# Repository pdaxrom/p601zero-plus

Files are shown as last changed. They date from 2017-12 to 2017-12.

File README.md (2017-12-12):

## Pyldin-601 compatible retrocomputer.

[History](docs/HISTORY.md)

### Overview hardware version 2.0:

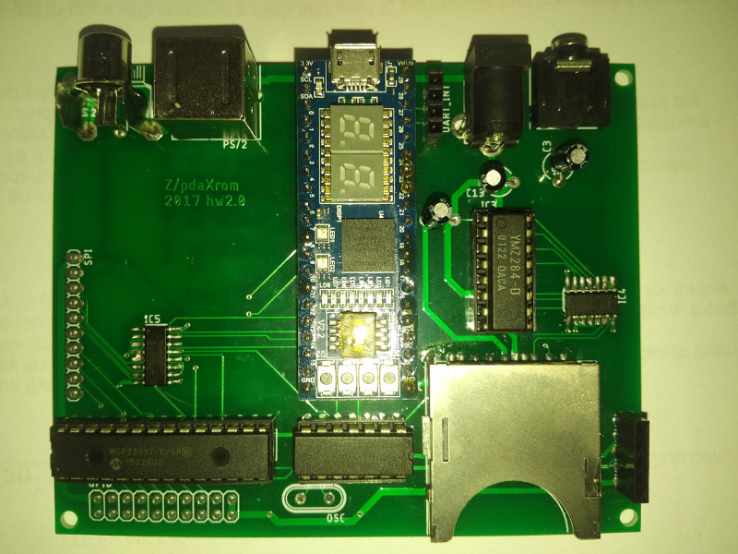
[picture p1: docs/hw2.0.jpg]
board version 2.0


 Function | Description 
----|----
CPU | [System 11 - VHDL 68HC11](http://members.optusnet.com.au/jekent/system11/)
FPGA| [Lattice MachXO2-4000HC module](http://www.stepfpga.com)
RAM | Builtin FPGA 4KB and/or external static serial ram 2x128KB
ROM | Builtin FPGA BOOTROM 2KB
Keyboard | PS/2
Serial port | 1 serial port and 1 UART (rx/tx only)
Parallel port | 2x8bit
Video | TV (color, 8bit DAC)
Audio | YMZ284-D (mono)
Storage | MMC/SD
Other | Onboard SPI, 4 CS ports and Reset.

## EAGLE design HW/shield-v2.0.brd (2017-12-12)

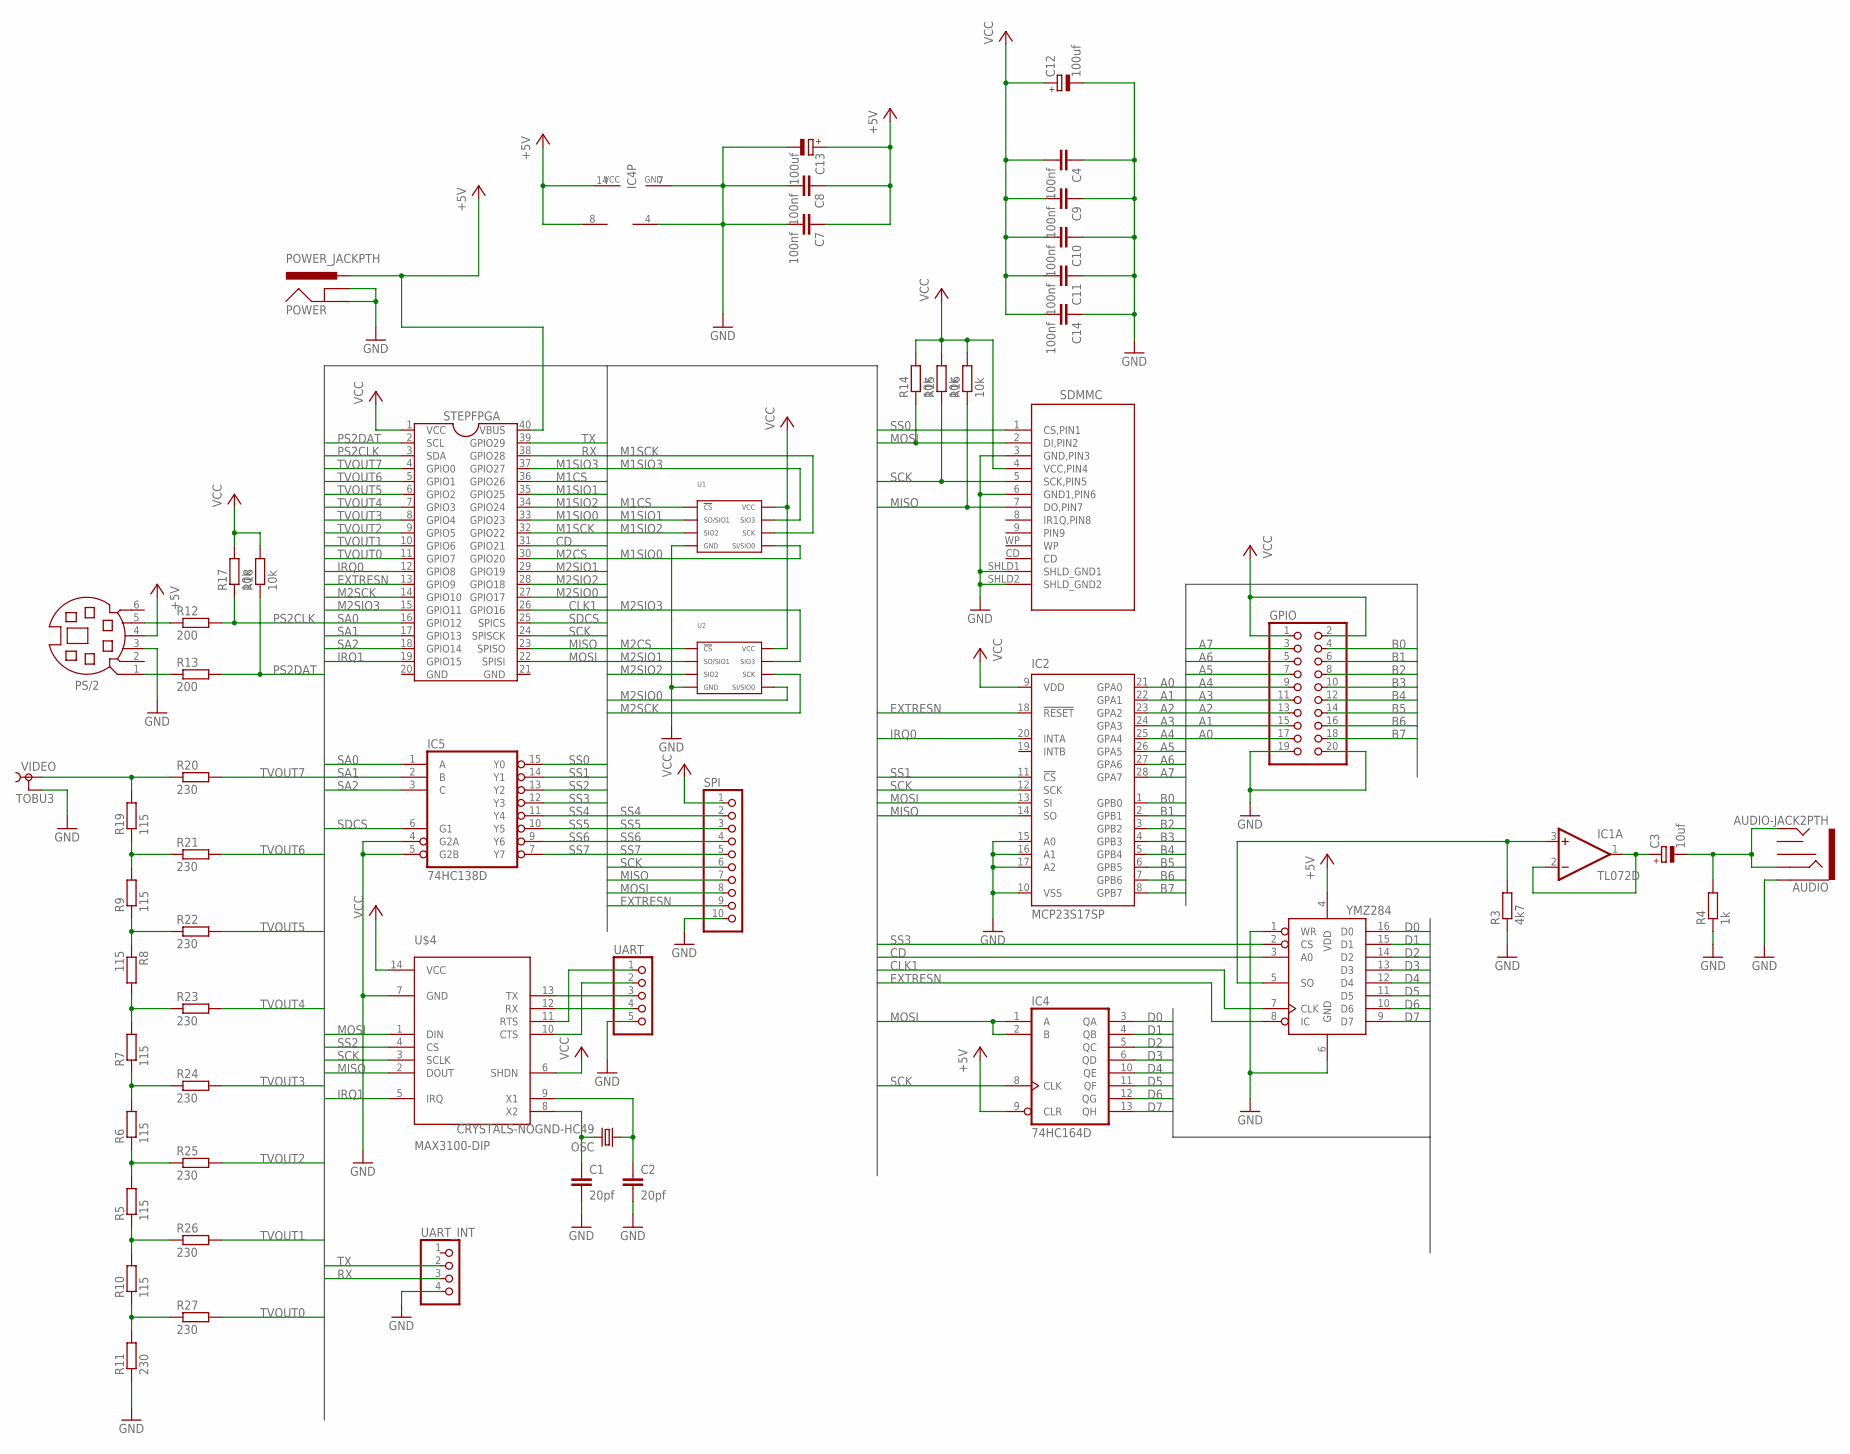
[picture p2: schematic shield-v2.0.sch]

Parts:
AUDIO: AUDIO-JACK2PTH; AUDIO-JACK
C1, C2: 20pf; 1206
C3: 10uf; E5-5
C4, C7, C8, C9, C10, C11, C14: 100nf; 1206
C12, C13: 100uf; E5-5
GPIO: PINHD-2X10; 2X10
IC1: TL072D; SO08
IC2: MCP23S17SP; DIL28-3
IC3: YMZ284; DIL16
IC4: 74HC164D; SO14
IC5: 74HC138D; SO16
OSC: CRYSTALS-NOGND-HC49; HC49
POWER: POWER_JACKPTH; POWER_JACK_PTH
PS/2: MD06SS; MDIN06SS
R3: 4k7; R1206
R4: 1k; R1206
R5, R6, R7, R8, R9, R10, R19: 115; R1206
R11, R20, R21, R22, R23, R24, R25, R26, R27: 230; R1206
R12, R13: 200; R1206
R14, R15, R16, R17, R18: 10k; R1206
SDMMC: FCI_SD_SOCKET; SD-MMC_SOCKET-PP
SPI: PINHD-1X10; 1X10
STEPFPGA: STEPFPGA; DIL40
U1, U2: 23A1024/23LC1024-I/SN; 23A1024_SOIC-8
U$4: MAX3100-DIP; DIL14
UART: PINHD-1X5; 1X05
UART_INT: PINHD-1X4; 1X04
VIDEO: TOBU3

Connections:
+5V: C7.1, C8.1, C13.+, IC1.8 (V+), IC3.4 (VDD), IC4.9 (CLR), IC4.14 (VCC), POWER.PWR, PS/2.4, STEPFPGA.40 (VBUS)
A0: GPIO.17, IC2.21 (GPA0)
A1: GPIO.15, IC2.22 (GPA1)
A2: GPIO.13, IC2.23 (GPA2)
A3: GPIO.11, IC2.24 (GPA3)
A4: GPIO.9, IC2.25 (GPA4)
A5: GPIO.7, IC2.26 (GPA5)
A6: GPIO.5, IC2.27 (GPA6)
A7: GPIO.3, IC2.28 (GPA7)
B0: GPIO.4, IC2.1 (GPB0)
B1: GPIO.6, IC2.2 (GPB1)
B2: GPIO.8, IC2.3 (GPB2)
B3: GPIO.10, IC2.4 (GPB3)
B4: GPIO.12, IC2.5 (GPB4)
B5: GPIO.14, IC2.6 (GPB5)
B6: GPIO.16, IC2.7 (GPB6)
B7: GPIO.18, IC2.8 (GPB7)
CD: IC3.3 (A0), STEPFPGA.31 (GPIO21)
CLK1: IC3.7 (CLK), STEPFPGA.26 (GPIO16)
D0: IC3.16 (D0), IC4.3 (QA)
D1: IC3.15 (D1), IC4.4 (QB)
D2: IC3.14 (D2), IC4.5 (QC)
D3: IC3.13 (D3), IC4.6 (QD)
D4: IC3.12 (D4), IC4.10 (QE)
D5: IC3.11 (D5), IC4.11 (QF)
D6: IC3.10 (D6), IC4.12 (QG)
D7: IC3.9 (D7), IC4.13 (QH)
EXTRESN: IC2.18 (!RESET), IC3.8 (IC), SPI.9, STEPFPGA.13 (GPIO9)
GND: AUDIO.SLEEVE, C1.2, C2.2, C4.1, C7.2, C8.2, C9.1, C10.1, C11.1, C12.-, C13.-, C14.1, GPIO.19, GPIO.20, IC1.4 (V-), IC2.10 (VSS), IC2.15 (A0), IC2.16 (A1), IC2.17 (A2), IC3.1 (WR), IC3.6 (GND), IC4.7 (GND), IC5.4 (G2A), IC5.5 (G2B), IC5.8 (GND), POWER.GND, POWER.GNDBREAK, PS/2.3, R3.1, R4.1, R11.1, SDMMC.3 (GND,PIN3), SDMMC.6 (GND1,PIN6), SDMMC.SHLD1 (SHLD_GND1), SDMMC.SHLD2 (SHLD_GND2), SPI.10, STEPFPGA.20 (GND), STEPFPGA.21 (GND), U1.4 (GND), U2.4 (GND), U$4.7 (GND), UART.5, UART_INT.4, VIDEO.2, VIDEO.2@1 (2), VIDEO.2@2 (2)
IRQ0: IC2.20 (INTA), STEPFPGA.12 (GPIO8)
IRQ1: STEPFPGA.19 (GPIO15), U$4.5 (IRQ)
M1CS: STEPFPGA.36 (GPIO26), U1.1 (CS')
M1SCK: STEPFPGA.32 (GPIO22), U1.6 (SCK)
M1SIO0: STEPFPGA.33 (GPIO23), U1.5 (SI/SIO0)
M1SIO1: STEPFPGA.35 (GPIO25), U1.2 (SO/SIO1)
M1SIO2: STEPFPGA.34 (GPIO24), U1.3 (SIO2)
M1SIO3: STEPFPGA.37 (GPIO27), U1.7 (SIO3)
M2CS: STEPFPGA.30 (GPIO20), U2.1 (CS')
M2SCK: STEPFPGA.14 (GPIO10), U2.6 (SCK)
M2SIO0: STEPFPGA.27 (GPIO17), U2.5 (SI/SIO0)
M2SIO1: STEPFPGA.29 (GPIO19), U2.2 (SO/SIO1)
M2SIO2: STEPFPGA.28 (GPIO18), U2.3 (SIO2)
M2SIO3: STEPFPGA.15 (GPIO11), U2.7 (SIO3)
MISO: IC2.14 (SO), R16.1, SDMMC.7 (DO,PIN7), SPI.7, STEPFPGA.23 (SPISO), U$4.2 (DOUT)
MOSI: IC2.13 (SI), IC4.1 (A), IC4.2 (B), R14.1, SDMMC.2 (DI,PIN2), SPI.8, STEPFPGA.22 (SPISI), U$4.1 (DIN)
unnamed: C1.1, OSC.2, U$4.8 (X2)
unnamed: U$4.13 (TX), UART.3
unnamed: U$4.12 (RX), UART.4
unnamed: U$4.11 (RTS), UART.1
unnamed: U$4.10 (CTS), UART.2
unnamed: C2.1, OSC.1, U$4.9 (X1)
unnamed: IC1.3 (+IN), IC3.5 (SO), R3.2
unnamed: C3.+, IC1.1 (OUT), IC1.2 (-IN)
unnamed: R19.2, R20.1, VIDEO.1
unnamed: AUDIO.RING, AUDIO.TIP, C3.-, R4.2
unnamed: R9.2, R19.1, R21.1
unnamed: R8.1, R9.1, R22.1
unnamed: R7.2, R8.2, R23.1
unnamed: R6.2, R7.1, R24.1
unnamed: R5.2, R6.1, R25.1
unnamed: R5.1, R10.2, R26.1
unnamed: R10.1, R11.2, R27.1
unnamed: PS/2.5, R12.1
unnamed: PS/2.1, R13.1
PS2CLK: R12.2, R17.1, STEPFPGA.3 (SDA)
PS2DAT: R13.2, R18.1, STEPFPGA.2 (SCL)
RX: STEPFPGA.38 (GPIO28), UART_INT.3
SA0: IC5.1 (A), STEPFPGA.16 (GPIO12)
SA1: IC5.2 (B), STEPFPGA.17 (GPIO13)
SA2: IC5.3 (C), STEPFPGA.18 (GPIO14)
SCK: IC2.12 (SCK), IC4.8 (CLK), R15.1, SDMMC.5 (SCK,PIN5), SPI.6, STEPFPGA.24 (SPISCK), U$4.3 (SCLK)
SDCS: IC5.6 (G1), STEPFPGA.25 (SPICS)
SS0: IC5.15 (Y0), SDMMC.1 (CS,PIN1)
SS1: IC2.11 (!CS), IC5.14 (Y1)
SS2: IC5.13 (Y2), U$4.4 (CS)
SS3: IC3.2 (CS), IC5.12 (Y3)
SS4: IC5.11 (Y4), SPI.2
SS5: IC5.10 (Y5), SPI.3
SS6: IC5.9 (Y6), SPI.4
SS7: IC5.7 (Y7), SPI.5
TVOUT0: R27.2, STEPFPGA.11 (GPIO7)
TVOUT1: R26.2, STEPFPGA.10 (GPIO6)
TVOUT2: R25.2, STEPFPGA.9 (GPIO5)
TVOUT3: R24.2, STEPFPGA.8 (GPIO4)
TVOUT4: R23.2, STEPFPGA.7 (GPIO3)
TVOUT5: R22.2, STEPFPGA.6 (GPIO2)
TVOUT6: R21.2, STEPFPGA.5 (GPIO1)
TVOUT7: R20.2, STEPFPGA.4 (GPIO0)
TX: STEPFPGA.39 (GPIO29), UART_INT.2
VCC: C4.2, C9.2, C10.2, C11.2, C12.+, C14.2, GPIO.1, GPIO.2, IC2.9 (VDD), IC5.16 (VCC), R14.2, R15.2, R16.2, R17.2, R18.2, SDMMC.4 (VCC,PIN4), SPI.1, STEPFPGA.1 (VCC), U1.8 (VCC), U2.8 (VCC), U$4.6 (SHDN), U$4.14 (VCC)

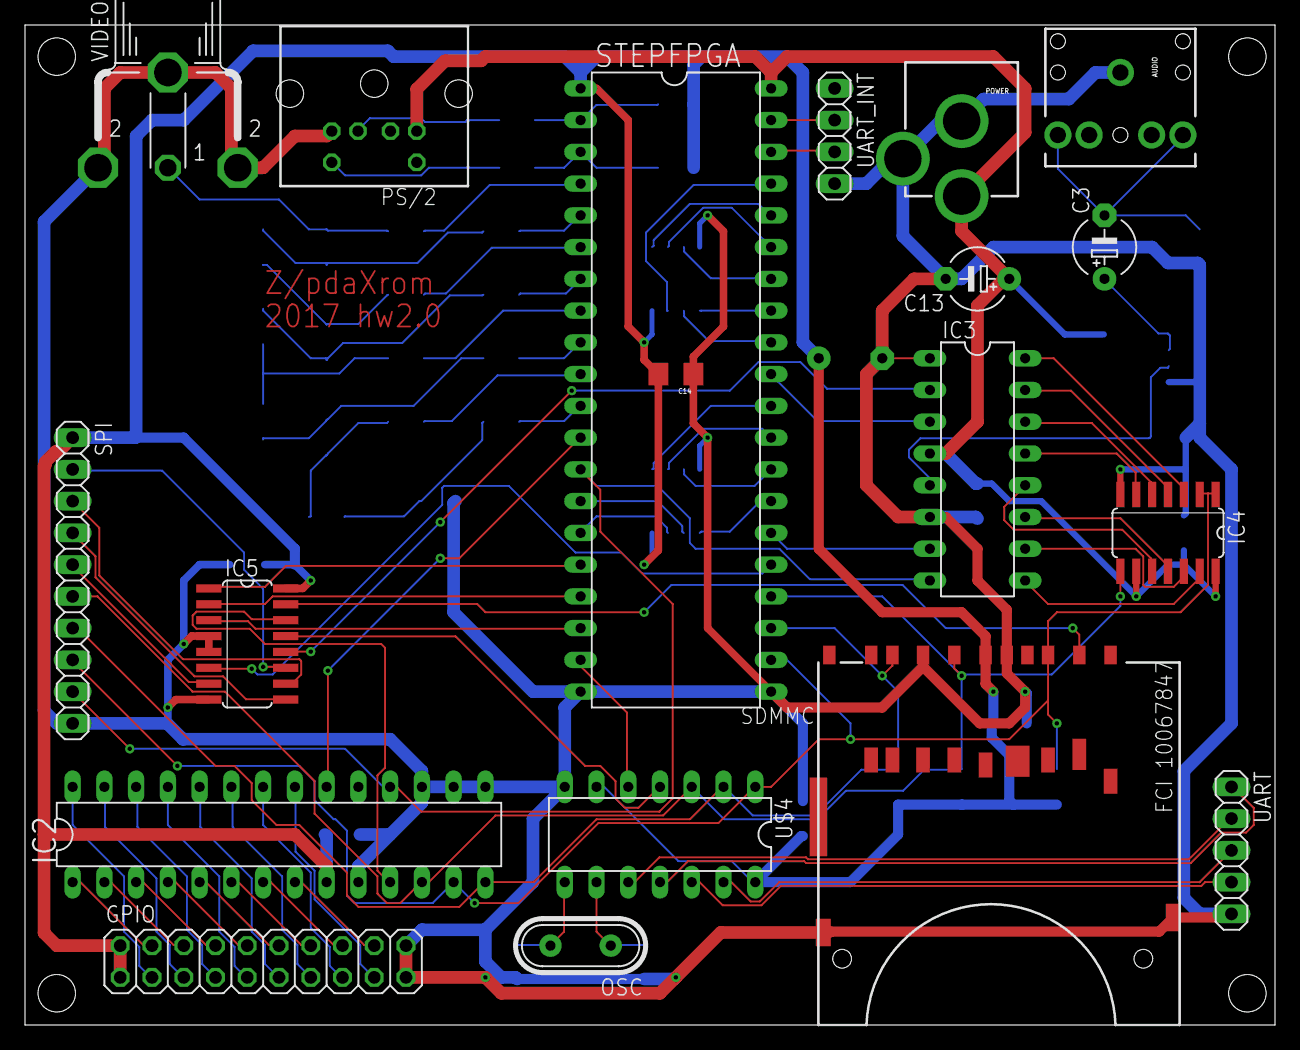
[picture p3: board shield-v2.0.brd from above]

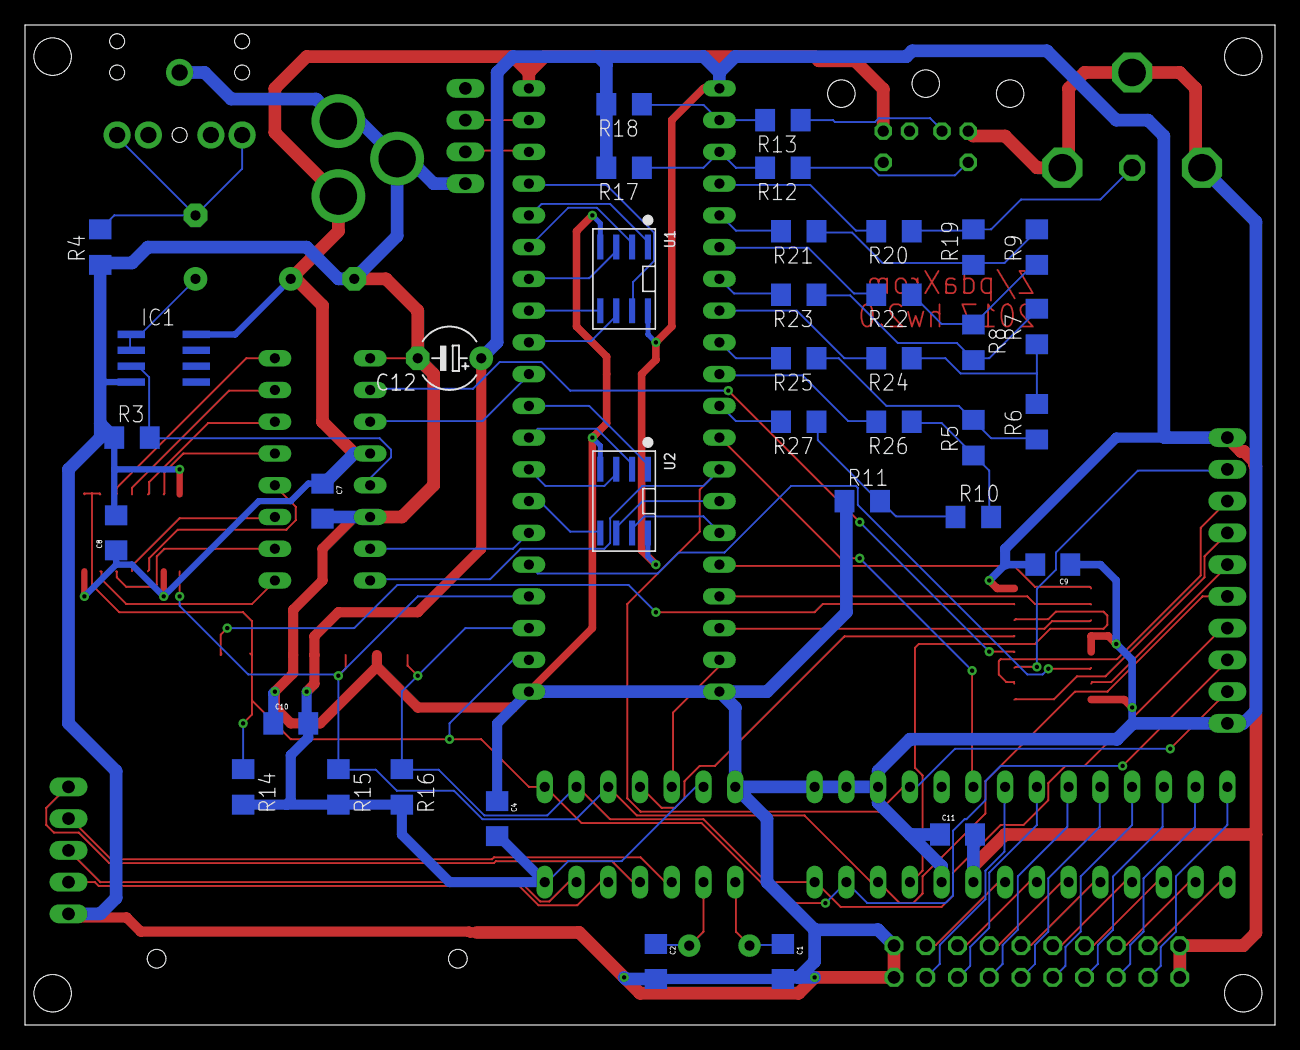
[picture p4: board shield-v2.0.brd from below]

Board: 2 copper layers, 100.0 x 80.0 mm, 56 parts (37 on the bottom side), 90 nets.

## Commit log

2017-12-12 initial hardware version 2.0
    [DRILEGEND.CFG, shield-v2.0.brd, shield-v2.0.sch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]
2017-12-12 board photo
2017-12-15 initial board support
2017-12-15 fixed dma logic with fast cpu

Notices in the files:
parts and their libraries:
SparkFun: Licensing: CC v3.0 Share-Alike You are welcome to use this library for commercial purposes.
